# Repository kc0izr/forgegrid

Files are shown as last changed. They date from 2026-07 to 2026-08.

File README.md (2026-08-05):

# ForgeGrid

ForgeGrid is an engineering-first OpenSCAD system for modular card, gaming,
workshop, and desktop accessories.

## Release

**v0.3.1-alpha**

This release corrects the ForgeLock datum/orientation bug found in v0.3.0-alpha.

## What changed

- All printable test parts now begin at **Z = 0**.
- Rail geometry is constructed from axis-aligned solids rather than a rotated
  2D extrusion.
- Channel geometry and labels use the same bottom datum.
- Added `FG-CONN-000`, a small geometry verification print.
- Rebuilt `FG-CONN-200` using the corrected connector library.

## Print order

1. Print `prototypes/FG-CONN-000/FG-CONN-000.scad`.
2. Confirm every piece is flat on the build plate in your slicer.
3. If it looks correct, print
   `prototypes/FG-CONN-200/FG-CONN-200.scad`.

All dimensions are millimeters.

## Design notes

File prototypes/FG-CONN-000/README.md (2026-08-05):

# FG-CONN-000 Datum Verification

This is a quick geometry check before printing FG-CONN-200.

1. Render with F6.
2. Export STL.
3. Open the STL in your slicer.
4. Use the slicer's "place on bed" or layer-preview tools to confirm that all
   four coupons begin at Z=0.
5. Verify there are no floating islands on the first layer.
6. Print without supports.

If all four coupons sit flat and print cleanly, continue to FG-CONN-200.

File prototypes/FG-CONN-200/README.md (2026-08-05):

# FG-CONN-200 Engagement Length Test

All variants use the validated 0.25 mm clearance.

## Before printing

Print or inspect `../FG-CONN-000/FG-CONN-000.scad` first.

## Variants

- ENG-010
- ENG-015
- ENG-020
- ENG-025
- ENG-030

Choose the shortest engagement that provides smooth operation, negligible
play, and satisfactory twist resistance.

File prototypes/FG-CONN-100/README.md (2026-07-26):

# FG-CONN-100 — ForgeGuide sliding-fit calibration

FG-CONN-100 is the first ForgeGrid print. It validates a 45-degree,
self-supporting V-guide before any final lock, magnet, or anti-lift mechanism
is added. The open-top receiver removes the long internal bridge found in the
withdrawn v0.2.1-alpha fixture.

## What it prints

Five labelled pairs are laid out as separate pieces in one OpenSCAD scene.
For each row, the left piece is the labelled rail and the right piece is its
matching open-top V-guide receiver. Match by row:

| Pair | Clearance |
| --- | ---: |
| C1 | 0.10 mm |
| C2 | 0.15 mm |
| C3 | 0.20 mm |
| C4 | 0.25 mm |
| C5 | 0.30 mm |

Lower the rail into the receiver's open V-guide, then slide it along its long
axis toward the closed end. The channel's closed end is the mechanical stop.
The rail can intentionally lift out: this fixture tests the guide profile only,
not the final retention mechanism.

## Print settings

- Printer baseline: Anycubic Kobra 2 Neo
- Material: PLA or PLA+
- Nozzle: 0.4 mm
- Layer height: 0.20 mm
- Walls: 3
- Infill: 15% gyroid (or your normal structural infill)
- Supports: off
- Brim: off

Print all pieces flat as supplied. There are no internal roof bridges or
unsupported horizontal surfaces in this revision.

## Test procedure

1. Let the parts cool completely and remove any brim/stringing.
2. Try every matching rail/channel pair by hand—do not force a tight pair.
3. For each pair, record insertion smoothness, side-to-side wobble, removal
   feel, stop feel, and visible print defects in `RESULTS.csv`.
4. Pick the tightest pair that inserts smoothly without force, binds neither at
   entry nor near the stop, and has no objectionable rattle.
5. Photograph the winning pair beside its labels and add a short note.

## Acceptance target

The preferred baseline should lower into the guide with light pressure, slide
without sticking, reach a clear positive stop, and have only slight perceptible
side play. This is a profile-fit experiment, **not** a structural-load,
magnet, or retention test.

## Next result needed

Return the chosen C-number plus printer, material, nozzle, layer height, and
any notes about bridge quality. That result will set `FG_SLIDING_CLEARANCE` for
the next ForgeLock revision.

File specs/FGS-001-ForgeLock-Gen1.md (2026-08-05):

# FGS-001: ForgeLock Gen1

Status: Provisional

## Confirmed
- Sliding clearance: 0.25 mm
- Build datum: intended print surface at Z=0
- Supports: none for test coupons

## Under test
- Engagement length
- Magnet placement
- Mechanical stop
- Anti-rattle preload
- Wear behavior

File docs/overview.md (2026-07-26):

# ForgeGrid overview

ForgeGrid develops 3D-printable, modular collector-workstation components from
a shared OpenSCAD library. The project validates a connector before applying it
to card sorters, deck docks, dice trays, and related modules.

The first engineering question is fit: which clearance performs reliably on
the target printer and material? FG-CONN-100 answers that question before
adding magnets, preload tabs, or product geometry.

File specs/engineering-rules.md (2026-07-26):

# ForgeGrid engineering rules

1. Use millimetres.
2. Put printer tuning in `FG_Config.scad`; put engineering dimensions in
   `FG_Standards.scad`.
3. Public modules start with `fg`; private helpers start with `_fg`.
4. A production module must include its module ID and revision.
5. A connector change requires a corresponding printable regression fixture.
6. Avoid unsupported overhangs and supports unless documented and approved.
7. Treat a selected fit as printer/material specific until replicated.

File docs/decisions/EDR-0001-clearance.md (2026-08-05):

# EDR-0001: ForgeLock Sliding Clearance

- Status: Approved for current baseline
- Evidence: FG-CONN-100
- Selected variant: C4
- Selected clearance: 0.25 mm

C4 provided smooth insertion and removal without perceptible wobble.

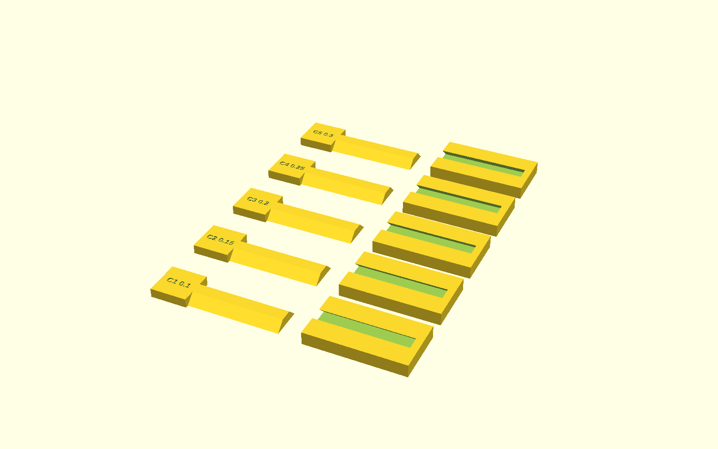
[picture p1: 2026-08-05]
prototypes/FG-CONN-100/FG-CONN-100-preview.png

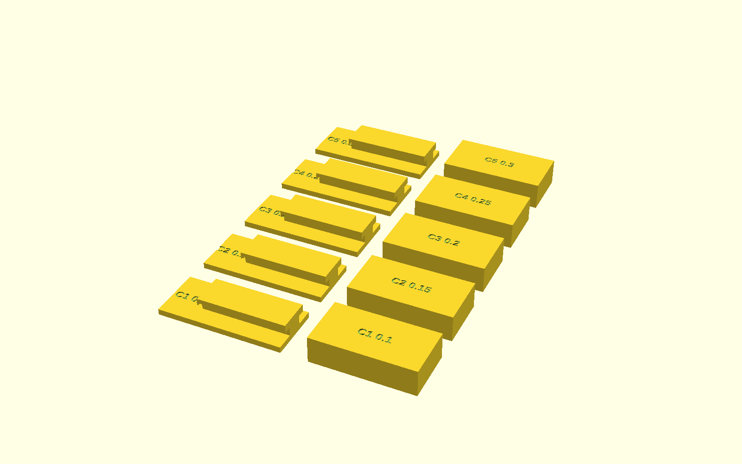
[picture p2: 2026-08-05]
prototypes/FG-CONN-100/FG-CONN-100.png

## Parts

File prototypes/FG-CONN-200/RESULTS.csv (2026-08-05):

experiment_id | prototype | variant | engagement_mm | clearance_mm | printer | material | nozzle_mm | layer_height_mm | insertion_score_1_5 | removal_score_1_5 | wobble_score_1_5 | vertical_play_score_1_5 | twist_resistance_score_1_5 | overall_score_1_5 | pass_fail | notes
FGX-0002 | FG-CONN-200 | ENG-010 | 10 | 0.25 | Anycubic Kobra 2 Neo |  | 0.4 | 0.20
FGX-0002 | FG-CONN-200 | ENG-015 | 15 | 0.25 | Anycubic Kobra 2 Neo |  | 0.4 | 0.20
FGX-0002 | FG-CONN-200 | ENG-020 | 20 | 0.25 | Anycubic Kobra 2 Neo |  | 0.4 | 0.20
FGX-0002 | FG-CONN-200 | ENG-025 | 25 | 0.25 | Anycubic Kobra 2 Neo |  | 0.4 | 0.20
FGX-0002 | FG-CONN-200 | ENG-030 | 30 | 0.25 | Anycubic Kobra 2 Neo |  | 0.4 | 0.20

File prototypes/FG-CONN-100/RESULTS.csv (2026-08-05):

experiment_id | date | printer | material | nozzle_mm | layer_height_mm | pair | clearance_mm | insertion_fit | wobble | removal_feel | stop_feel | bridge_quality | selected | notes
FGX-0001 | 2026-07-26 | Anycubic Kobra 2 Neo | PLA+ | 0.4 | 0.2 | C1 | 0.10 | Will not Insert | N/A | N/A | N/A | N/A | N/A | N/A
FGX-0001 | 2026-07-26 | Anycubic Kobra 2 Neo | PLA+ | 0.4 | 0.2 | C2 | 0.15 | Only inserts a small distances | N/A | N/A | N/A | N/A | N/A | N/A
FGX-0001 | 2026-07-26 | Anycubic Kobra 2 Neo | PLA+ | 0.4 | 0.2 | C3 | 0.20 | Fits snug, but will not go all the way in | No Wobble | removes fine | Does not enter all the way | No issues | N/A
FGX-0001 | 2026-07-26 | Anycubic Kobra 2 Neo | PLA+ | 0.4 | 0.2 | C4 | 0.25 | Smooth Insert | No Wobble | Smooth removeal | Stops at the end point | No issues | Yes
FGX-0001 | 2026-07-26 | Anycubic Kobra 2 Neo | PLA+ | 0.4 | 0.2 | C5 | 0.30 | Loose insert | Some Wobble | Loose removal | Stops at the end point | No issues | No

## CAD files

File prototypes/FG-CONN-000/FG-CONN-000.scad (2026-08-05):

/*
FG-CONN-000
Datum and Geometry Verification Fixture
ForgeGrid v0.3.1-alpha

Open in the slicer after export and confirm all four coupons touch Z=0.
*/

include <../../lib/FG_Config.scad>;
include <../../lib/FG_Standards.scad>;
include <../../lib/FG_Connectors.scad>;

test_length = 20;
spacing_x = 35;
spacing_y = 46;

translate([0, 0, 0])
    fgForgeLockRailTestPart(test_length, "R-A");

translate([spacing_x, 0, 0])
    fgForgeLockChannelTestPart(test_length, "C-A");

translate([0, spacing_y, 0])
    fgForgeLockRailTestPart(30, "R-B");

translate([spacing_x + 10, spacing_y, 0])
    fgForgeLockChannelTestPart(30, "C-B");

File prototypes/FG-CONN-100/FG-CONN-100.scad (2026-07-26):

/* FG-CONN-100 | ForgeGuide sliding-fit fixture | v0.2.2-alpha
   Every piece prints flat without supports or brim. Each row contains one
   labelled 45-degree rail coupon and one matching open-top V-guide receiver. */

include <../../lib/FG_Connectors.scad>;

FG_CONN_100_CLEARANCES = [0.10, 0.15, 0.20, 0.25, 0.30];
FG_CONN_100_ROW_PITCH = 24;
FG_CONN_100_PAIR_GAP = 8;

module fgConn100Row(index, clearance) {
    label = str("C", index+1, " ", clearance);
    fgForgeGuideRailBlock(clearance=clearance, label=label);
    translate([FG_FG_RAIL_LENGTH + 12 + FG_CONN_100_PAIR_GAP, 0, 0])
        fgForgeGuideChannelBlock(clearance=clearance);
}

for (i=[0:len(FG_CONN_100_CLEARANCES)-1])
    translate([0, i*FG_CONN_100_ROW_PITCH, 0])
        fgConn100Row(i, FG_CONN_100_CLEARANCES[i]);

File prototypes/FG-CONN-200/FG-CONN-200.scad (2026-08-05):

/*
FG-CONN-200
ForgeLock Gen1 Engagement Length Test
ForgeGrid v0.3.1-alpha

Every standalone part is generated with its bottom at Z=0.
*/

include <../../lib/FG_Config.scad>;
include <../../lib/FG_Standards.scad>;
include <../../lib/FG_Connectors.scad>;

engagement_lengths = [10, 15, 20, 25, 30];

for (i = [0 : len(engagement_lengths)-1]) {
    length = engagement_lengths[i];
    label = str(
        "ENG-",
        length < 10 ? "00" :
        length < 100 ? "0" : "",
        length
    );

    y = i * FG_TEST_ROW_PITCH;

    translate([0, y, 0])
        fgForgeLockRailTestPart(
            length=length,
            label=label
        );

    translate([length + FG_TEST_PAIR_GAP, y, 0])
        fgForgeLockChannelTestPart(
            length=length,
            label=label
        );
}

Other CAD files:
examples/forgelock-example.scad
tests/connector-regression.scad

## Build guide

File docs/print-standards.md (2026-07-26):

# Print standards

The initial baseline is an Anycubic Kobra 2 Neo using a 0.4 mm nozzle, PLA or
PLA+, 0.20 mm layers, three walls, and 15% gyroid infill. Production parts
should avoid supports. Record deviations from this baseline with every
prototype result; they affect connector fit.

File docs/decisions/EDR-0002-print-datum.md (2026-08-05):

# EDR-0002: Printable Part Datum

- Status: Approved
- Date: 2026-08-04

## Decision

Every standalone printable ForgeGrid module must occupy `Z >= 0`, with its
intended print-bed contact surface located at `Z = 0`.

## Reason

FG-CONN-200 v0.3.0-alpha exposed a connector orientation error caused by
rotating an extruded 2D profile. The profile extended below the build plane.

## Implementation

ForgeLock rail and channel geometry is now built from axis-aligned solids.
Rotated profile extrusion is not used for standalone test parts.

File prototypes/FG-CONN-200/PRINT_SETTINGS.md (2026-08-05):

# Print Settings

- Printer: Anycubic Kobra 2 Neo
- Nozzle: 0.4 mm
- Layer height: 0.20 mm
- Walls: 3
- Top/bottom: 5
- Infill: 15%
- Supports: Off
- Orientation: As generated

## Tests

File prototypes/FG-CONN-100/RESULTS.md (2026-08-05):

# FG-CONN-100 Result

Winner: **C4 / 0.25 mm**

- Smooth insertion
- Smooth removal
- No perceptible wobble

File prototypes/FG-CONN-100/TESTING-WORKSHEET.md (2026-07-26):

# FG-CONN-100 testing worksheet

Experiment ID: ____________________   Date: ____________________

Printer: _________________________   Material: __________________

Nozzle / layer: __________________   Temperature: _______________

| Pair | Clearance | Inserts smoothly? | Wobble | Stop feel | Bridge quality | Winner? | Notes |
| --- | ---: | --- | --- | --- | --- | --- | --- |
| C1 | 0.10 mm | | | | | | |
| C2 | 0.15 mm | | | | | | |
| C3 | 0.20 mm | | | | | | |
| C4 | 0.25 mm | | | | | | |
| C5 | 0.30 mm | | | | | | |

Chosen baseline: ___________________

Decision rationale: __________________________________________________________

____________________________________________________________________________

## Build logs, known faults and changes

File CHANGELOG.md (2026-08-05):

# Changelog

## 0.3.1-alpha - 2026-08-04

### Fixed
- Corrected rail geometry that extended below the Z=0 print datum.
- Corrected channel/test-part placement so every part rests flush on the bed.
- Replaced rotated profile extrusion with axis-aligned solid construction.

### Added
- FG-CONN-000 datum and geometry verification fixture.
- Datum assertions and parameter validation.
- Updated print-check instructions.

### Retained
- Validated ForgeLock clearance: 0.25 mm.
- FG-CONN-200 engagement candidates: 10, 15, 20, 25, and 30 mm.

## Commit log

2026-07-26 Initial prototype with connectors only
    [RESULTS.csv, connector-regression.scad]
2026-07-26 Building the Connectors
    [FG-CONN-100.scad, RESULTS.csv, connector-regression.scad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]
2026-07-26 Fixing issues
    [FG-CONN-100.scad]
2026-08-05 Add FG-CONN-200 engagement length test
    Add FG-CONN-200 engagement length test
    [FG-CONN-200.scad, RESULTS.csv]
2026-08-05 ForgeGrid v0.3.1-alpha
    FG-CONN-200
    ForgeLock Gen1 Engagement Length Test
    ForgeGrid v0.3.1-alpha
    [FG-CONN-000.scad, FG-CONN-200.scad, RESULTS.csv]
